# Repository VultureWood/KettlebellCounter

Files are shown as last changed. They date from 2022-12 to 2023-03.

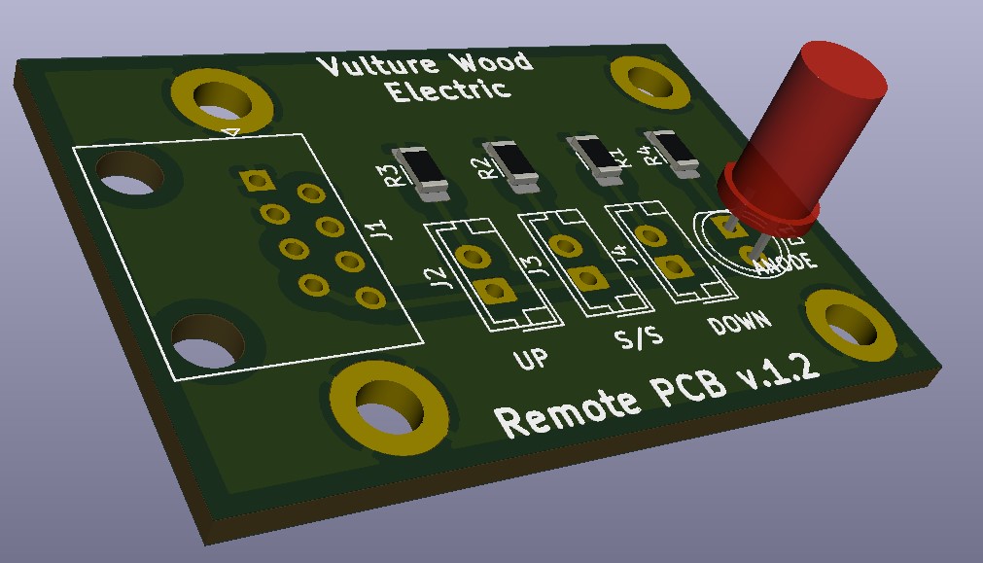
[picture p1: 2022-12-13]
PCB/Records/KBC_Remote/Remote_pcb_3d.jpg

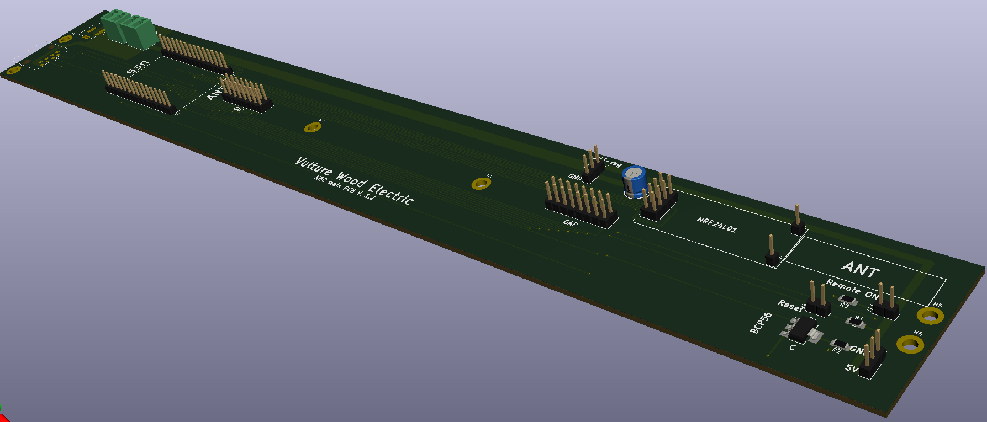
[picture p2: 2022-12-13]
PCB/Records/KBC_Main_PCB/KBC_Main_PCB_3d.png

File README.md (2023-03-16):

# KettlebellCounter
Open Source instruction and code, which allow any tech savvy kettlebell athlete to build their own counter.  

This project was my very first large scale project were I got to integrate all my skills obtained at DTU - Technical University of Denmark.  

The Kettlebell Counter project was a Start Up under DTU - Skylab and more than 100 counters have been sold.  
Obvious, looking back, the projects have its flaws and some solutions are not as refined or clever, as I would like to believe I could come up with now.  
However, the counters work and some have been used daily since 2019.  

I developed the counters for the 2019 IKMF European championship while I was finishing my M.Sc.EE at DTU.  

The counter is not just an up/down counter, it has lots of features like ladders, intervals and a dedicated pentathlon function, and it can be remote controlled by a radio link.  

My idea was that the counter could be used by the athlete for training as well as for competition, and everyone could bring their counters for a competition and they would all work together via remote control.
I’ve produced and sold the aforementioned 100+ counters in the frame of my start-up Company "Vulture Wood Electric", before getting an awesome job building radars, which came with a non-compete clause.  

I therefore closed the start-up, and after a 2 years grace periode, where no legal claims or injunctions have been filed, I can now freely share my project with the community.  

This project is share under the GitHub license, which like the Creative commons license, allows for free non-commercial use.  

The intent is for kettlebell enthusiasts to be able to build their own counter which can be used both for both individual training and competitions.  

Have fun and keep lifting  

Best regards  

Erik Hofman-Bang  
Denmark, December 2022.  

- Video instructions for PCB mounting with soldering instructions: https://youtu.be/9TzXEnOfvD8  

- Video instructions for modifying the 3D printed frame and assembly: "coming soon"

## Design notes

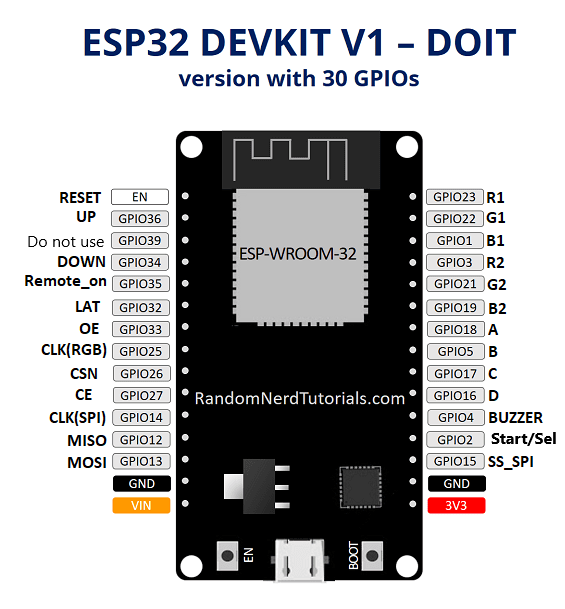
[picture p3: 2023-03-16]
Software_for_ESP32/ESP32-Pinout-for-VW_KBC_RGB_matrix_w_SPI.png

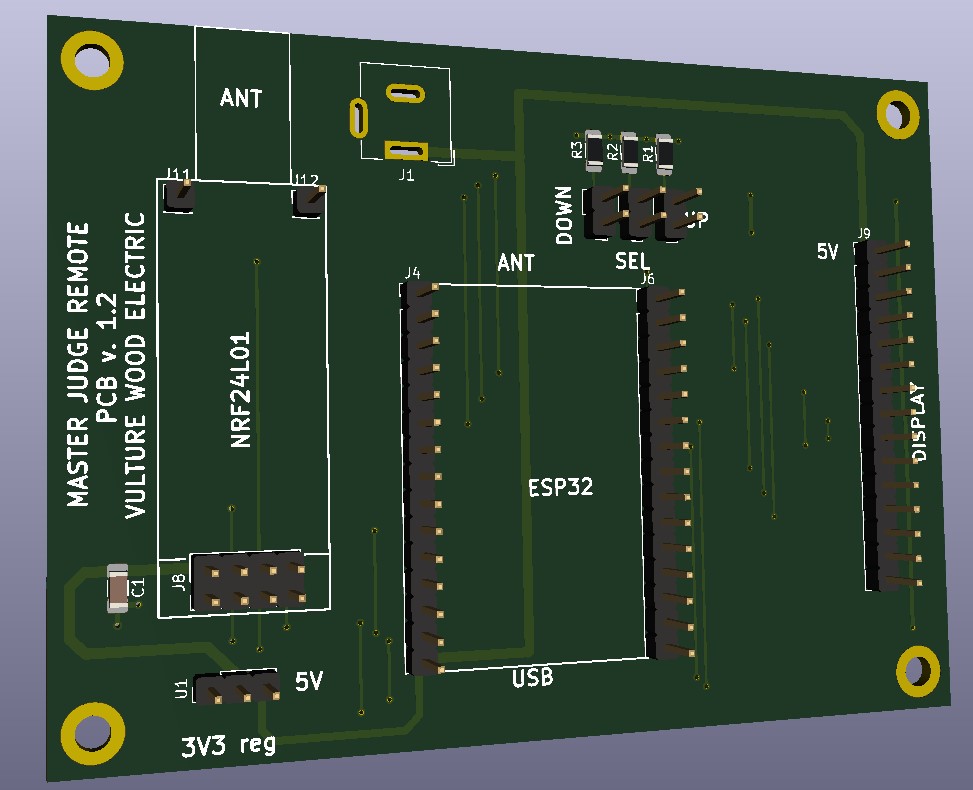
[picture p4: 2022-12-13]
PCB/Records/Master_Judge_Remote/Master_Judge_PCB_3D.jpg

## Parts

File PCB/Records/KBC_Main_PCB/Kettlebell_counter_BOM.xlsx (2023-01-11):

Reference Name | Value | Pieces | Comment | Aliexpress
MAIN PCB
U1 (J1/J2) | 1 x 15 pinHeader | 2 | 2.54 mm dupont female header 15 pins | https://www.aliexpress.com/item/32988745109.html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
R1,R2,R3 | 2.2k Ohm Resistor | 3 | 2k2 SMD 1206 resistor | https://www.aliexpress.com/item/1005001794416354.html?curPageLogUid=xTvxAzRKwdO4
J3,J6 | 2x8 Connector | 2 | IDC Box head connector for Ribbon cable 2x8 | https://www.aliexpress.com/item/1005004266492521.html?ad_pvid=20221128110945313599986753300016118840_3&s=p
J7 | Barrel Jack | 1 | 5.5 x 2.1 mm Female DC Power Jack Plug | https://www.aliexpress.com/item/4000585704812.html?spm=a2g0o.order_list.0.0.6a0f1802Q6Qj3E
J8 | 2 x 4 Pinheader | 1 | 2.54 mm dupont female header 8 pins (2x4) | https://www.aliexpress.com/item/32982421676.html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
J5,J12 | 2pin screw terminal | 2 | 2 pin Phoenix KF103 Screw terminal 5.08mm pitch | https://www.aliexpress.com/item/4000012676176.html?curPageLogUid=UXMHhe5J44D7
J10 | AMS1117-3.3V | 1 | 3 Pin PCB with AMS1117-3.3V and capacitors | https://www.aliexpress.com/item/32774098119.html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
J11 | RJ45 Plug | 1 | RJ45 Metal 8 Pin Female PCB | https://www.aliexpress.com/item/32694863099.html?pdp_ext_f=%7B%22sku_id%22%3A%2260585625209%22%7D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
C1 | 10uF | 1 | 10uF SMD 1206 capacitor, not necessary if capacitors on AMS117 | https://www.aliexpress.com/item/1005002532606555.html?curPageLogUid=5Q6LUYoGYaFm
Q1 | BCP56 | 1 | Transistor NPN BJT in SOT223 package | https://www.aliexpress.com/item/32714187815.html?spm=a2g0o.order_list.0.0.6a0f1802Q6Qj3E
H1-H6 | PCB Standoffs | 6 | Stand Offs, M3*18+6 | https://www.aliexpress.com/item/4000888322479.html?curPageLogUid=1wqWb8rG2vht
PCB | VW Main PCB V1.3 | 1 | The PCB for the Kettlebell Counter
MCU | ESP32-30 pin | 1 | ESP32 doit devkit v1 pinout | https://www.aliexpress.com/item/32864722159.html?spm=a2g0o.order_list.0.0.6a0f1802Q6Qj3E
Power Supply | 5V | 1 | 5V power supply. 2.5A current, and 5.5-2.5mm plug | https://www.aliexpress.com/item/33058333264.html?curPageLogUid=6rzwCtLGh5pI
 |  |  | Depending on you country. Select the plug and voltage suited
 |  |  | 2.5 A should be enough, normal current is ~2.1A, Choose a semi long wire >1m
Buzzer | 5 V Square | 1 | Round Piezoelectric buzzer | https://www.aliexpress.com/item/32783807336.html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
LED Screens | 64x32 P5 | 2 | LED Display P5 32*64 Pixles 320*160mm Panel 1/16 Scan Indoor RGB Full Color HUB75 | https://www.aliexpress.com/item/32870054325.html?spm=a2g0o.order_list.0.0.6a0f1802Q6Qj3E
Radio | NRF24L01 | 1 | Either the Base module with PCB antenna | https://www.aliexpress.com/item/1005004204908059.html?curPageLogUid=XcxRy4gxmFWM
 |  |  | or the extended with Big antenna, PA, and LNA | https://www.aliexpress.com/item/32831025394.html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
Reset Switch | button | 1 | Momentary push button, any kind will do. | https://www.aliexpress.com/item/1005004561204413.html?curPageLogUid=nWRDyEQSEv7G
Remote/local Switch | Flip Switch | 1 | On/OFF toggle switch, Any will do but I prefer this one: KNS-1 | https://www.aliexpress.com/item/33051456822.html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
Wires |  |  | Assorted wires for soldering swithces
NUT | 1/4-20 UNC | 1 | Hex nut 1/4" for mid frame, so tripod can be fixed | https://www.aliexpress.com/item/1005003345732578.html?curPageLogUid=IAchS2ZKnS4B
Bolt | 1/4-20 UNC | 1 | A bolt UNC 1/4-20, for driving the nut into it´s place in the mid frame | https://www.aliexpress.com/item/1005003504983409.html?curPageLogUid=XN0bGadiK4bz
Tripod | with 1/4-20 unc thread | 1 | Tripod to mount the counter on | https://www.aliexpress.com/item/1005003504983409.html?curPageLogUid=XN0bGadiK4bz
Remote
J11 | RJ45 Plug | 1 | RJ45 Metal 8 Pin Female PCB | https://www.aliexpress.com/item/32694863099.html?pdp_ext_f=%7B%22sku_id%22%3A%2260585625209%22%7D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
R1,R2,R3,R4 | 2.2k Ohm Resistor | 4 | 2k2 SMD 1206 resistor | https://www.aliexpress.com/item/32694862467.html?spm=a2g0o.order_list.0.0.6a0f1802Q6Qj3E
D1 | LED | 1 | 5mm LED with pre mounted wires and Holder | https://www.aliexpress.com/item/1005001992101233.html?curPageLogUid=z9fJW20eJ7ca
H1-H4 | PCB Standoffs | 4 | Stand Offs, M3*12+6 | https://www.aliexpress.com/item/4000888322479.html?curPageLogUid=1wqWb8rG2vht
PCB | Remote PCB V1.3 | 1 | The PCB for the Remote | Mounting holes a M3 (3.2mm) and spaced 30mm on the X axis and 22mm on the Y axis
 | M3 nuts | 4 | Nots for ocking the PCB in place
Cable | Cat 5 Patch | 1 | Ethernet Patch cable Straight through, NOT CROSSED, male-male, what ever length suits your purpose, Regardless of T-568B og T-568A. I choose this cable because it's cheap and available. I used T-568B cables but it shouldn't matter
Master Judge Remote
J4,J5,J9 | 1 x 15 pinHeader | 3 | 2.54 mm dupont female header 15 pins | https://www.aliexpress.com/item/32996636367.html?spm=a2g0o.order_list.0.0.6a0f1802Q6Qj3E
R1,R2,R3 | 2.2k Ohm Resistor | 3 | 2k2 SMD 1206 resistor | https://www.aliexpress.com/item/32694862467.html?spm=a2g0o.order_list.0.0.6a0f1802Q6Qj3E
J1 | Barrel Jack | 1 | 5.5 x 2.1 mm Female DC Power Jack Plug | https://www.aliexpress.com/item/4000585704812.html?spm=a2g0o.order_list.0.0.6a0f1802Q6Qj3E
H1-H4 | PCB Standoffs | 4 | Stand Offs, M3*18+6 | https://www.aliexpress.com/item/4000888322479.html?curPageLogUid=1wqWb8rG2vht
U1 | AMS1117-3.3V | 1 | 3 Pin PCB with AMS1117-3.3V and capacitors | https://www.aliexpress.com/item/32774098119.html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
C1 | 10uF | 1 | 10uF SMD 1206 capacitor, not necessary if capacitors on AMS117 | https://www.aliexpress.com/item/1005002532606555.html?curPageLogUid=5Q6LUYoGYaFm
J8 | 2 x 4 Pinheader | 1 | 2.54 mm dupont female header 8 pins (2x4) | https://www.aliexpress.com/item/32982421676.html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
Buttons | Push button | 3 | Momentary push button, any kind will do. | https://www.aliexpress.com/item/1005004561204413.html?curPageLogUid=nWRDyEQSEv7G
Display | 2,8" LCD Display | 1 | 2.8" 240x320 SPI TFT LCD | https://www.aliexpress.com/wholesale?catId=0&initiative_id=SB_20221130011202&origin=y
Extra | PCB Standoffs | 4 | Stand Offs, M3*18+6 +M3*12+6
Wires |  |  | Assorted wires for soldering swithces
Power Supply | 5V/2.5A | 1 | Important: the plug must match the Barrel jack DC 5.5-2.5 or DC 5.5-2.1 | https://www.aliexpress.com/item/33058333264.html?curPageLogUid=LnRn97kkHrKo

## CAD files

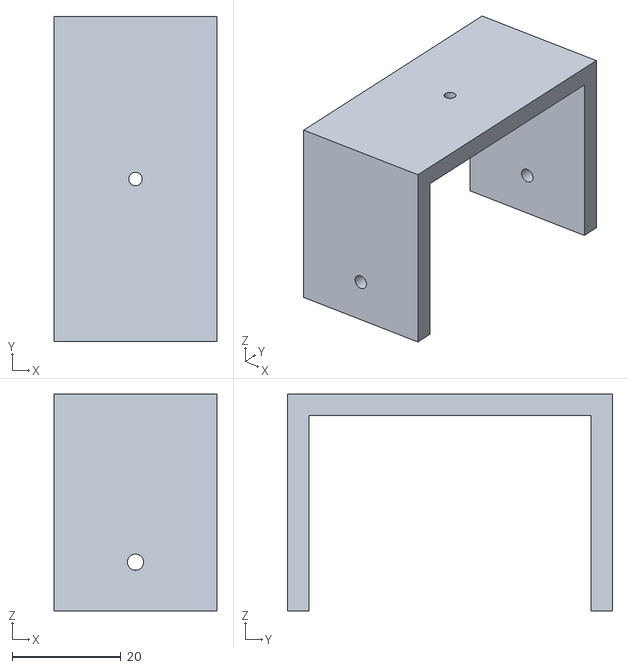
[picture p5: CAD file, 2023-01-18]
Mechanics/Frame_and_mounting_instructions/Top_Frame.stl
30.0 x 60.0 x 40.0

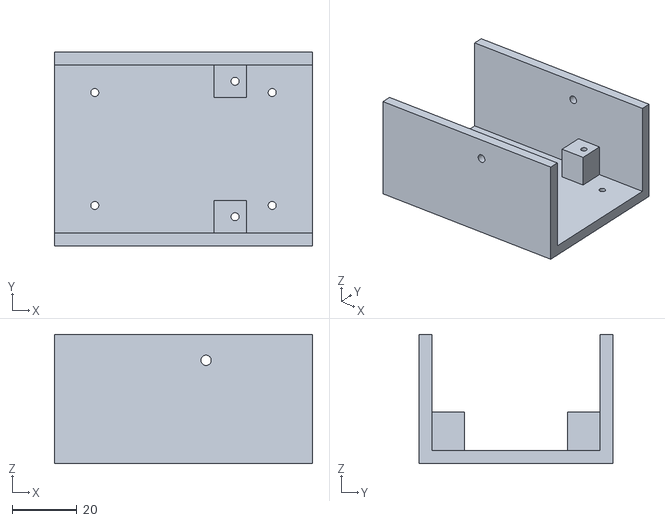
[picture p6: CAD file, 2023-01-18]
Mechanics/Frame_and_mounting_instructions/End_frame_R.stl
80.0 x 60.0 x 40.0

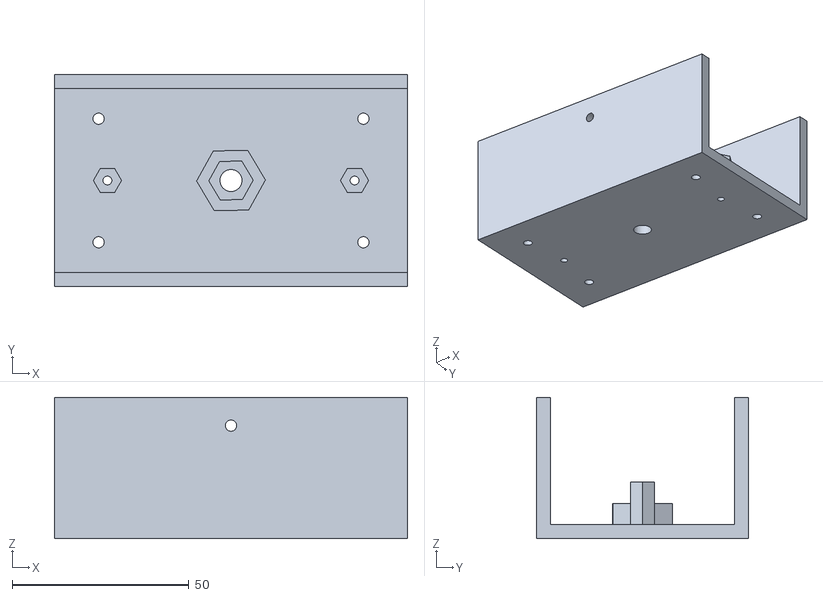
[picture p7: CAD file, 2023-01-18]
Mechanics/Frame_and_mounting_instructions/Mid_frame.stl
100.0 x 60.0 x 40.0

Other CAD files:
Mechanics/Frame_and_mounting_instructions/End_frame_L.stl

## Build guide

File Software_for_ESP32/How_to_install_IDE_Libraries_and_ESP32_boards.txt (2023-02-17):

Arduino IDE installation, Library download and board manager.

1) Arduino IDE:
Go to Arduino.cc and download the IDE to your computer. 
Follow the step shown, it should be staright forward, even with the new 2.0 IDE.

2) Libraries
Open you browser, and search for:

Adafruit_GFX.h.

Click the GitHub link. press the Green <Code> button , and select "downlaod ZIP"

Do this for:

RF24.h  (by nRF24) and P3RGB64x32MatrixPanel.h (by NeoCat) as well

Go to your Aarduino IDE again, and select: <Sketch> , <Include Library>, < Add .zip Library..>

A file explorer window (or similar) will open. Navigate to your downlaod folder and select one of the above mentioned files and click <Open>

Repeat this for the remaining two files 

3) adding ESP 32 boards to the IDE

Press <FileZ in the top left corner of the IDE, and select <Prefrences>

Almost at the bottom, insert "https://dl.espressif.com/dl/package_esp32_index.json" into the text field after "Additional boards manager URLs:

Press <OK>

Go to <Tools> , <Board:> and select <Boardmanager>

Tyoe in "ESP32" in to the text field in the top left corner under "BOARDS MANAGER" and press enter

PRess the "esp32 by Espressif Systems" and select the newest version to installation

4) Selecting the right board

Go to <Tools> , <Board:> , <esp32> and select the right ESP32 board. For me its "DOIT ESP32 DEVKIT V1"

You should now be able to compile the file.

When uploading... Remember that once it starts the actual uploading, the IDE polls the board, and you have to

press the "BOOT" button on the right side of the USB port to enable the upload procedure.

17/02-23 

\\Erik

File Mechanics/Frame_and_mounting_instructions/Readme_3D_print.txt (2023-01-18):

Print:

1x End_frame_Right.stl

1x End_frame_Left.stl

1x Mid_frame.stl

2x Top_Frame.stl

5 layer walls. PLA, 50% infill

Use Brim for support

Materials:

5 x 3D printed parts
2 x LED Matrix scrrens 64x32 P5
2 x Ribbon cables
1 x power cable
10 x M3x10 Socket head screws
6 x M3x6 button head screws
1 x 1/4-20 UNC Nut

Tools:
1 x 1/4-20 UNC Bolt , 1" or longer
Power drill
2.5mm drill
3.5mm drill
M3 Tap
11mm Wrench/Spanner 

Mounting:
Pre drill all vertical holes for M3 with a 2.5mm drill and then cut a thread with a M3 tap all the way through 
( 6 in each of the bottom parts, and 1 in each of the top part))

Drill all horizontal "screen mounitng holes" with a 3.2mm (3.5mm) drill ( 2 in each piece)

Mount a 1/4-20 UNC hex nut, with a 1/4-20 UNC bolt from the backside and force the nut into the hex shape in the MID_frame.

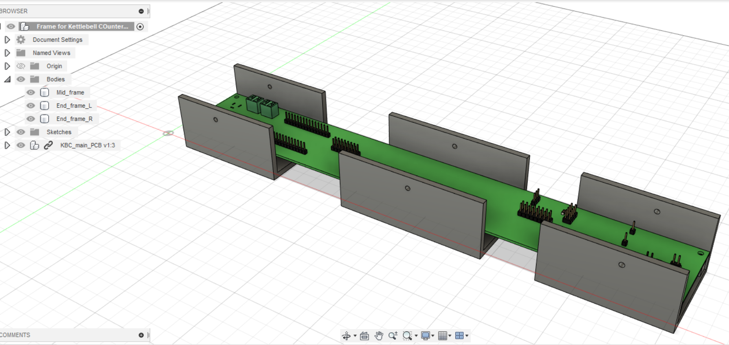
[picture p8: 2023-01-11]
Mechanics/CAD-files/Frame_3D_printed/Bottom_frames_and_PCB_principal_assembly.png

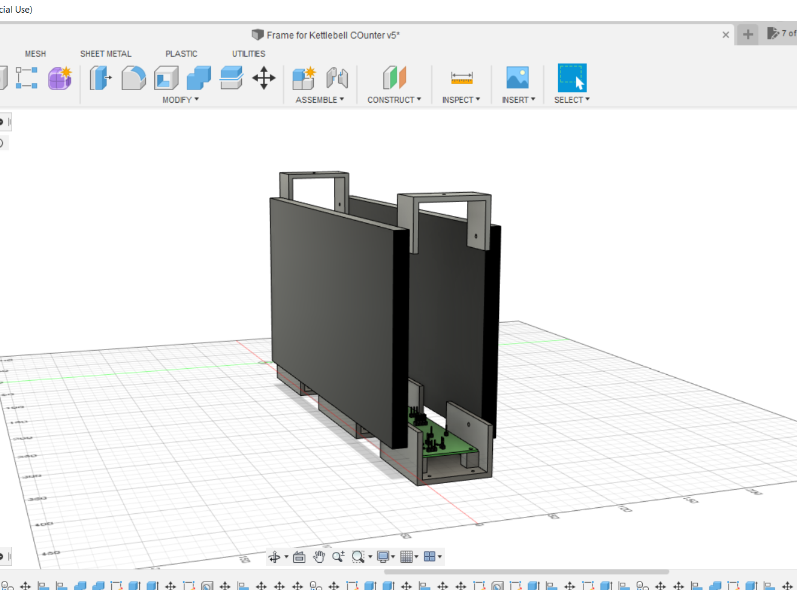
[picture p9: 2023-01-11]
Mechanics/CAD-files/Frame_3D_printed/Insta_pic_1.png

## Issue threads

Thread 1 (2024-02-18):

Frame and case for Master Judge remote

langatium, 2024-02-18:
I'm wondering if you could share details (casing and frame) for the master judge remote?

Vulture-in-the-woods, 2024-02-19:
Hi Heinz-Peter.
Thank you for your interest.
I currently have the project on hold while I’m doing a very large project, which takes up all my time and resources.
I have planed to review the whole design and project sometime this summer, but until the I’m unfortunately unable to accommodate your request.
Best Regards
Erik

langatium, 2024-02-19:
Hi Erik,

no worries, all best for your large project. Nevertheless big thanks for sharing the design of your timer. I'm nearly finished with the first one.

Best regards
Heinz

Vulture-in-the-woods, 2024-02-19:
That’s really great Heinz.
I’m so glad that people are building by the timers, although I didn’t get to finish all details.
Please let me know once you’ve build your timer. I’m in instagram as @vulturewood
//Erik

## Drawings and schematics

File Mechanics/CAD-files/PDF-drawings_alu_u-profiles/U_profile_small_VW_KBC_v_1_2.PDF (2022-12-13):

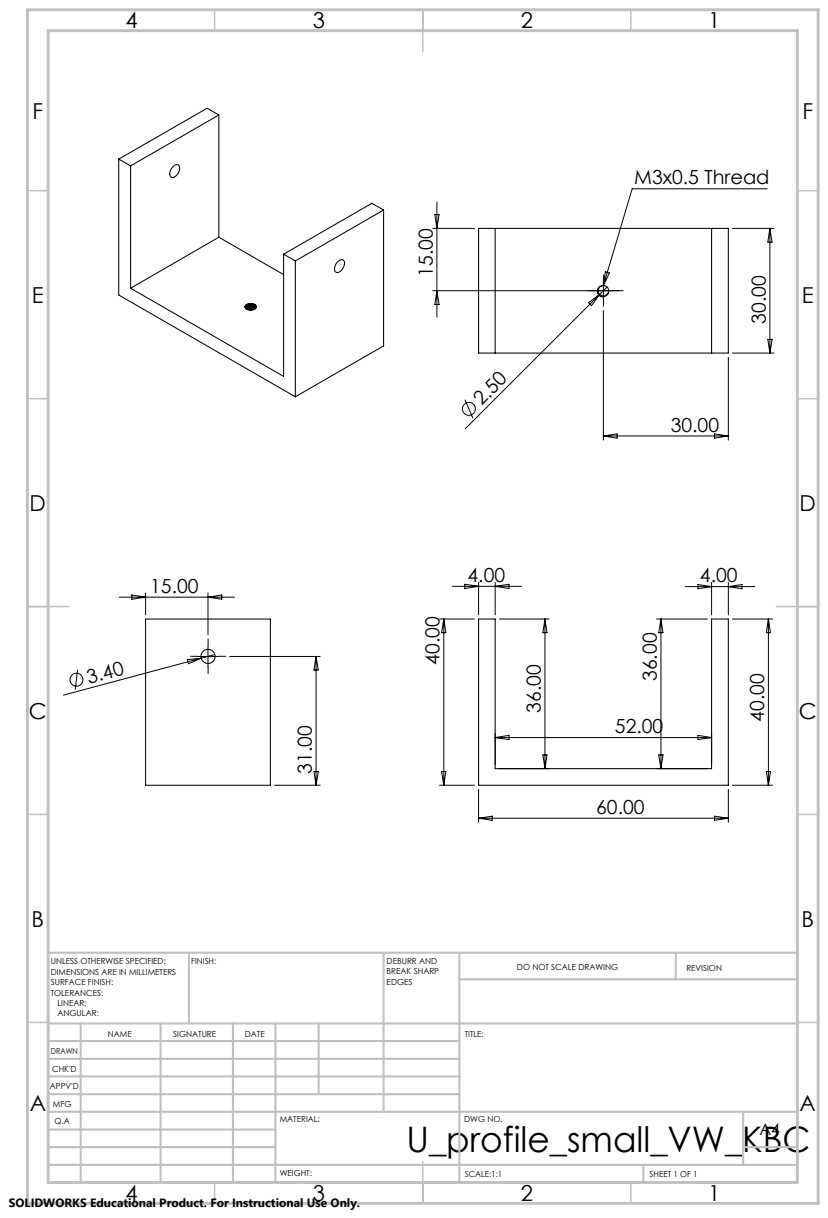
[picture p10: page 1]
M3x0.5 Thread; FINISH:; DEBURR AND; BREAK SHARP; DO NOT SCALE DRAWING; REVISION; SCALE:1:1; SHEET 1 OF 1

UNLESS OTHERWISE SPECIFIED:
DIMENSIONS ARE IN MILLIMETERS
SURFACE FINISH:
TOLERANCES:
LINEAR:
ANGULAR:

NAME | SIGNATURE | DATE | | | | TITLE:

DRAWN
CHK'D
APPV'D
MFG
Q.A | | | | MATERIAL: U_profile_small_VW_KBC | DWG NO. | A4

SOLIDWORKS Educational Product. For Instructional Use Only.

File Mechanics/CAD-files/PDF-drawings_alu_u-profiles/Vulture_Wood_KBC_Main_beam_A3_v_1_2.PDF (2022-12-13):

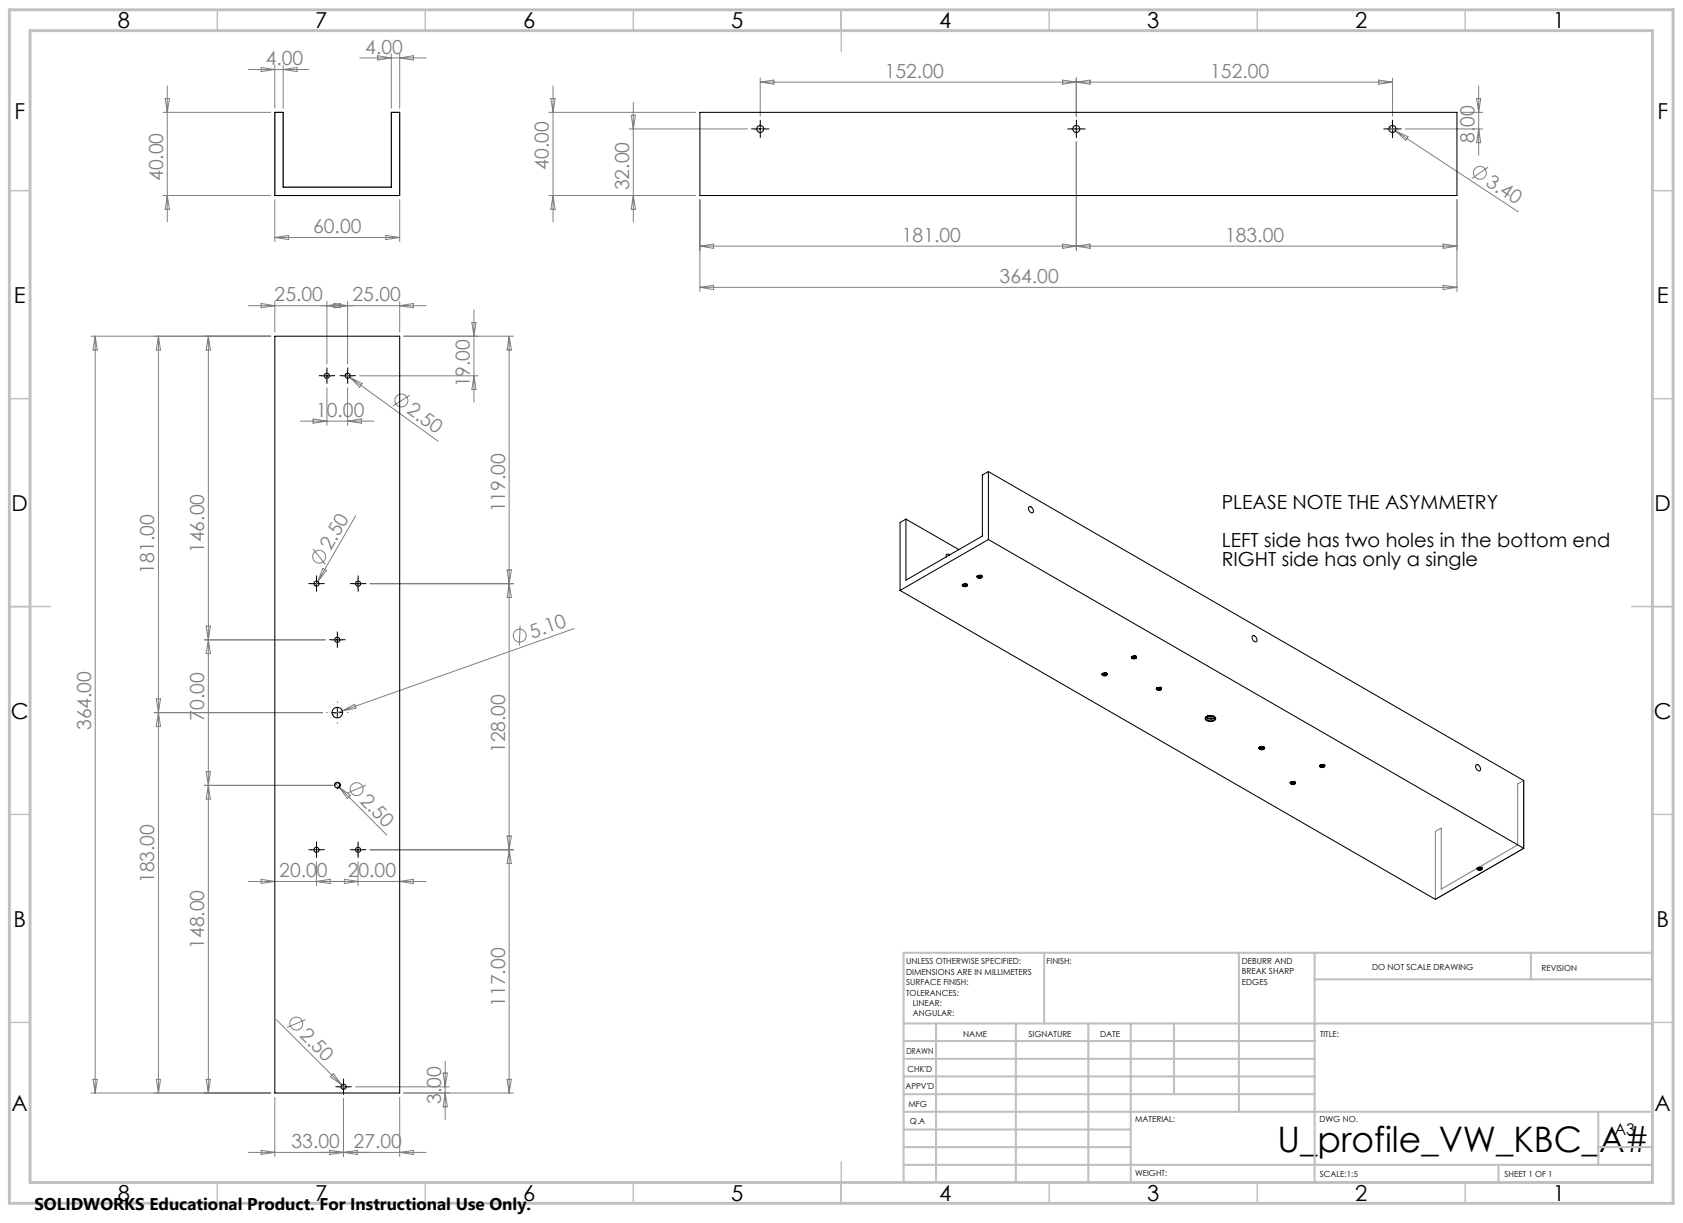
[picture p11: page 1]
FINISH:; DEBURR AND; BREAK SHARP; DO NOT SCALE DRAWING; REVISION; SCALE:1:5; SHEET 1 OF 1

PLEASE NOTE THE ASYMMETRY
LEFT side has two holes in the bottom end
RIGHT side has only a single

UNLESS OTHERWISE SPECIFIED:
DIMENSIONS ARE IN MILLIMETERS
SURFACE FINISH:
TOLERANCES:
LINEAR:
ANGULAR:

NAME | SIGNATURE | DATE | | | | TITLE:

DRAWN
CHK'D
APPV'D
MFG
Q.A | | | | MATERIAL: U_profile_VW_KBC_A# | DWG NO. | A3

SOLIDWORKS Educational Product. For Instructional Use Only.

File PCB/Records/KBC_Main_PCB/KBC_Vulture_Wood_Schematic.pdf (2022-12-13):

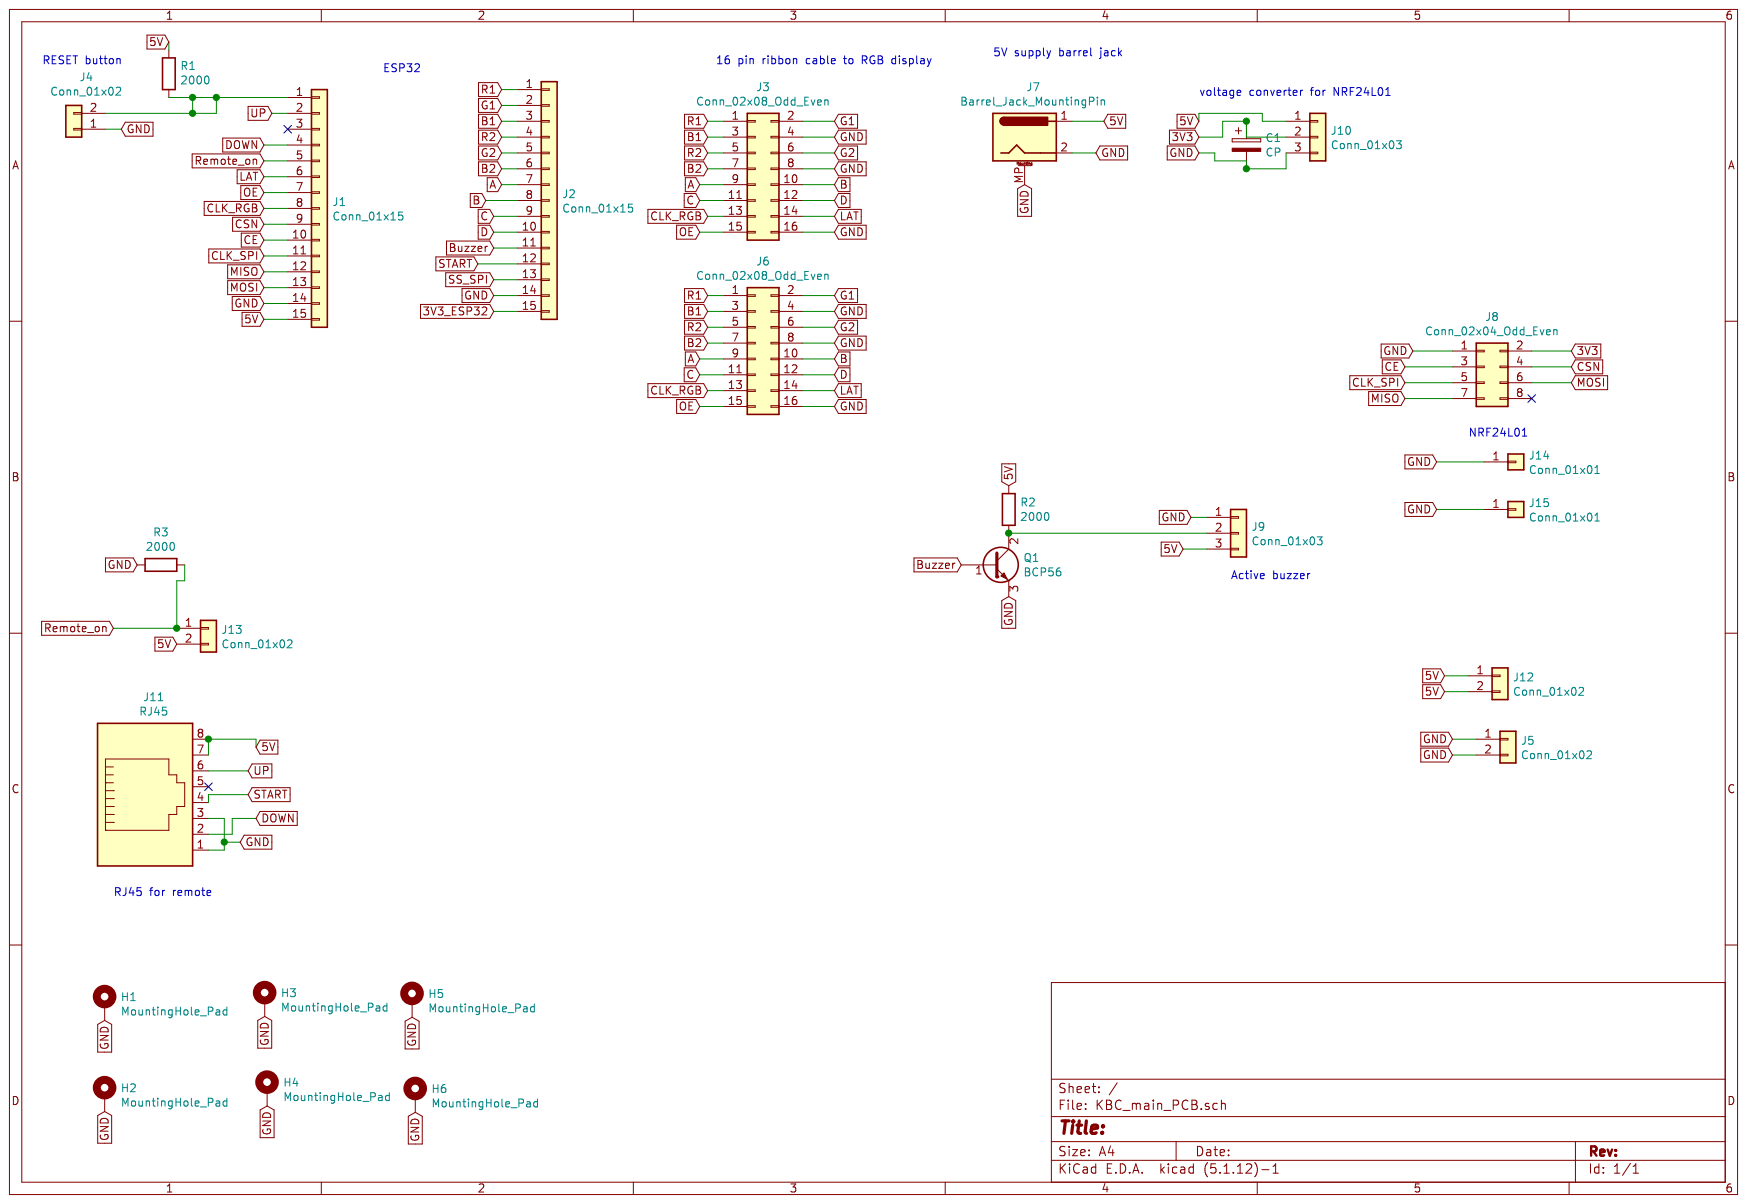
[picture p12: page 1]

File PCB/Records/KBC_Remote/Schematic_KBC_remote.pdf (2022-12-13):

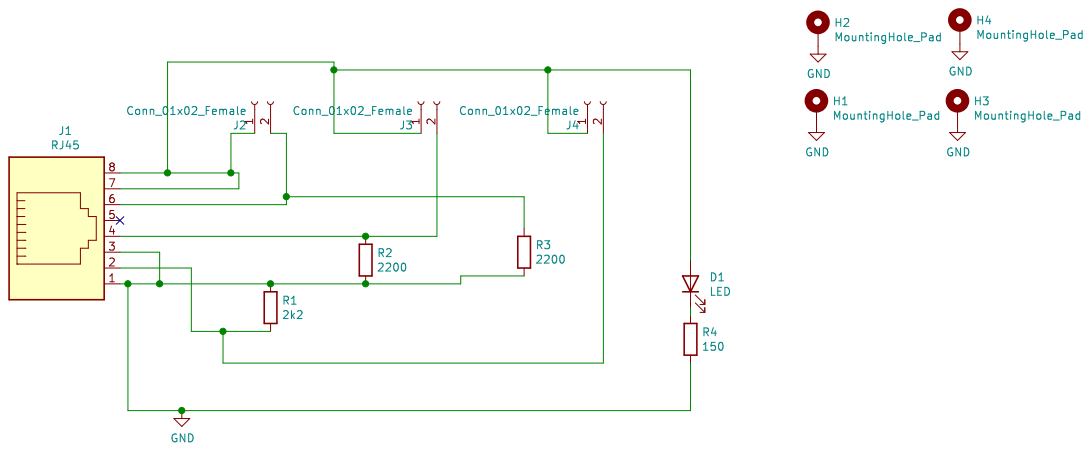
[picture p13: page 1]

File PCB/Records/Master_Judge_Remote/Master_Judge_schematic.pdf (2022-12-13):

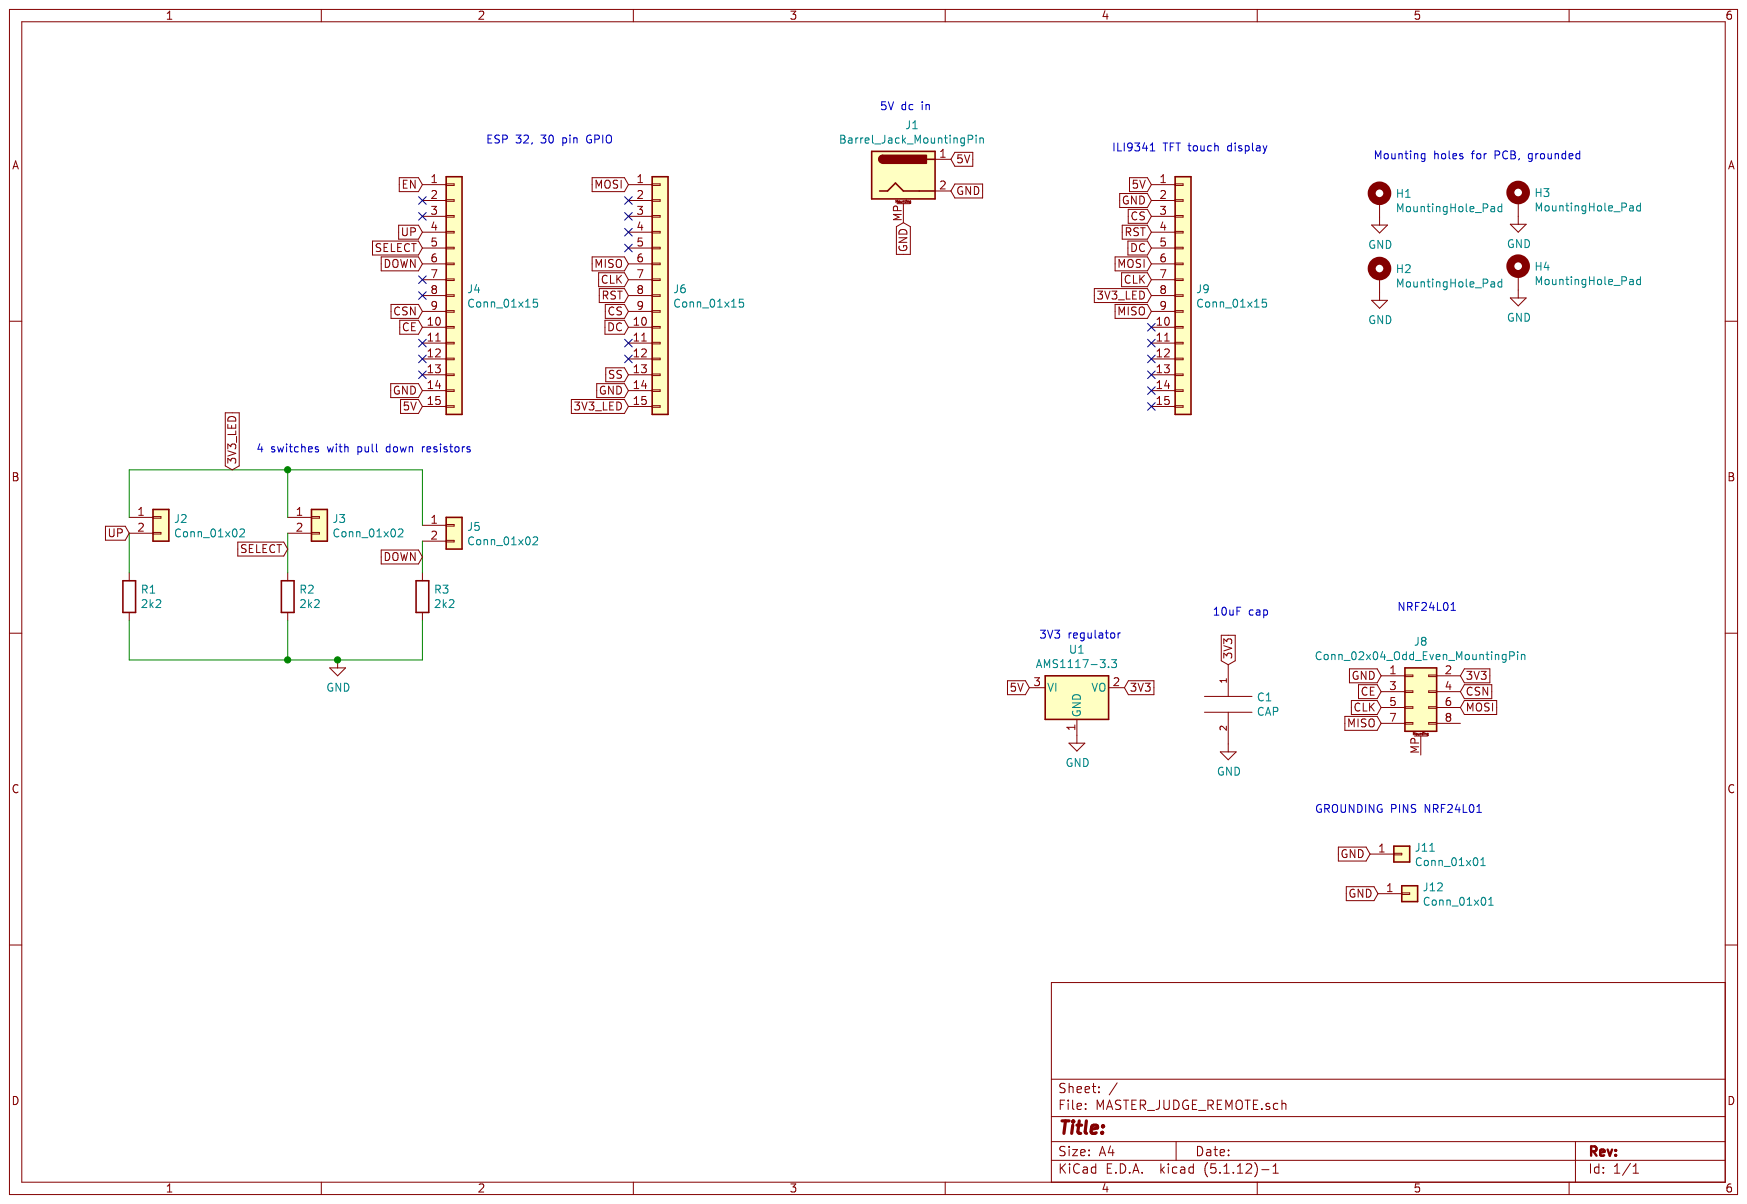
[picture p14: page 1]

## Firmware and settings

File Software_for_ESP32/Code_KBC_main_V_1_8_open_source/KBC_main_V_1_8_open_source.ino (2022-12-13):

/*
This code is the work of Erik Hofman-Bang, Denmark (the author)
For the project known as Vulture Wood Electric
These next ~4400 lines make up the main Kettlebell Counter including:
Base functions and Remote operation via radio/SPI link
Bluetooth functions have been erased, but as of 30/11-22 the menu point still exists 
This code is designed for an ESP32 and takes up 23% of storage and 4 % o dynamic memory

This code can be used and/or altered under the creative Commons license for all non-commercial purposes if the author is credited
*/

#include <Adafruit_GFX.h>   // Core graphics library
#include <P3RGB64x32MatrixPanel.h> // RGB display driver from NEOCAT github
// That is the library which contains the matrix.begin(); command which makes the watchdog timer panic
#include <SPI.h> // spi for radio use
#include <nRF24L01.h> // radio libraries
#include <RF24.h> // radio libraries  // 

// Radio pins
#define CE_PIN  27
#define CSN_PIN 26  
#define CLK_SPI 14 // 
#define MISO 12 // 
#define MOSI 13 //
#define SS 15 // 

//Matrix pins
#define R1 23
#define G1 22
#define BL1 1
#define R2 3
#define G2 21
#define BL2 19
#define pin_A 18
#define pin_B 5
#define pin_C 17
#define pin_D 16
#define CLK_RGB 25
#define LAT_RGB 32
#define OE_RGB 33

//////////////////////////////////////////////////////////
//
//  RADIO SPECIFIC VARIABLES ETC
//
//////////////////////////////////////////////////////////

bool doOnceRadio = true;
bool rpdPrint;
RF24 radio(CE_PIN,CSN_PIN);

unsigned long timeDifference;

const uint64_t pipe1 = 0xE8E8EEF0A1LL;;
const uint64_t pipe2 = 0xA2LL;  
const uint64_t pipe3 = 0xA3LL;
const uint64_t pipe4 = 0xA4LL;
const uint64_t pipe5 = 0xA5LL;
const uint64_t pipe6 = 0xA6LL;

// RADIO memory string

typedef struct {
  char filterChar[1];
  bool startBit;
  bool reset1;
  uint8_t setDiscipline;
  unsigned long setDuration;
  unsigned long masterMillis;
  bool returnResult;
  uint16_t result;
  bool switchChannel;
  bool reset2;
  } TXstruct;

  TXstruct message;
  TXstruct validMessage;

  // Matrix pin constructor
  //P3RGB64x32MatrixPanel matrix; // default constructor
P3RGB64x32MatrixPanel matrix(R1,G1,BL1,R2,G2,BL2,CLK_RGB,LAT_RGB,OE_RGB,pin_A,pin_B,pin_C,pin_D);

//////////////////////////////////////////
//
// Butten and buzzer pins
//
/////////////////////////////////////////

#define buttonPin 2   // select/menu
#define repButtonUP 36
#define repButtonDOWN 34
#define remote_on 35
#define BuzzerPin 4
uint16_t Buzzerfreq = 2000;
uint8_t BuzzerChannel = 0;
uint8_t BuzzerResolution = 8;
uint16_t BuzzerDuty = 128; // Volumen intensity in 8 bits, 125 (50%) will be loudest I think)

/////////////////////////////////////
//
// Variables for general functions.
//
////////////////////////////////////

int8_t countState = LOW;         // the current state of the output pin
int8_t buttonState;             // the current reading from the input pin
int8_t lastButtonState = LOW;   // the previous reading from the input pin
int8_t buttonStateRepUP;             // the current reading from the input pin
int8_t lastButtonStateRepUP = LOW; 
int8_t buttonStateRepDOWN;             // the current reading from the input pin
int8_t lastButtonStateRepDOWN = LOW; 
int8_t readingRepUP;
int8_t readingRepDOWN;
int8_t reading;
int8_t readingONEmenuUP;
long lastDebounceTimeONEmenuUP;
int8_t buttonStateONEmenuUP = 0;
int8_t lastbuttonStateONEmenuUP = 0;
uint8_t line; // for time_fractionPause
int8_t Menu = 1;
int8_t Select =0;
int8_t choiceMade =0;
uint16_t sum_CLEAN = 0;
uint16_t sum_CandP = 0;
uint16_t sum_JERK = 0;
uint16_t sum_HS = 0;
uint16_t sum_PP = 0;
uint16_t divider = 0 ;
int8_t run_pause=0;
int8_t doOnceTimer=1;
int8_t doOnceCounter=1;
int8_t doOnceCountdownTimer =1;
int8_t doOnceRepCounter = 0;  // for testing rep numbers
int8_t runStopRoutine =1;
int8_t CDT_hh_1 = 0;
int8_t CDT_mm_10 = 0;
int8_t CDT_mm_1 = 0;
int8_t CDT_ss_10 = 0;
int8_t CDT_ss_1 = 0;
int8_t CDT_menu = 1;
int8_t CDT_menu_Last =1;
int8_t CDT_var_val =0;
int8_t fourDigits = 0;
int8_t Pentathlon = 0;
int8_t doOncePentathlon =1;
int8_t Countdown = 0;
int8_t UPdownMenu =0;
uint8_t ONEmenuUP  =0;
int8_t doOnceUPdownMenu =1;
int8_t UpDown_var_val = 2;
int8_t doOnceCountdown =1;
int8_t setCountdownTimer =1;
int8_t CountdownTimer = 0;
int8_t CountUpTimer = 0 ;
int8_t Interval = 0;
int8_t doOnceInterval =1;
uint8_t XonYoff = 0;
int XOnctr = 1;
int XOntime = 60;
int XOntimeOLD = 0;
int YOffctr = 1;
int YOfftime = 60;
int YOfftimeOLD = 0;
int XOnYOffctr = 0;
uint8_t doOnceYOfftimeRUN = 1;
int16_t XonYoffRounds =1; 
int16_t XonYoffRoundsOLD =0; 
uint8_t doOnceXonYoff = 1;
uint8_t XOnYOfftimer =0;
uint8_t doOnceXOnYOfftimer = 1;
uint8_t XOntimeRUN = 1;
uint8_t YOfftimeRUN = 1;
uint8_t doOnceEndXOnYOff =1;
uint8_t MERKULIN = 0;
uint8_t EMOTM = 0;
uint8_t EMOTMtimer = 0;
uint8_t endOfEMOTM = 0;
uint8_t disciplineDisplay = 1;
uint8_t durationDisplay =0;
uint8_t doOnceremote =1;
uint8_t waitingForStartCommand = 1;
uint8_t DisciplineNOTset =1;

uint16_t sum_MERKULIN[]= {0,0,0,0,0,0,0,0,0,0,0,0,0,0,0,0,0,0,0,0,0,0,0,0,0,0,0,0,0,0,0,0,0,0,0,0,0,0,0,0,0,0,0,0,0,0,0,0,0,0,0,0,0,0,0,0,0,0,0,0,0,0,0,0,0,0,0,0,0,0,0,0,0,0,0,0,0,0,0,0,0,0,0,0,0,0,0,0,0,0,0,0,0,0,0,0,0,0,0,0,0,0};
uint8_t doOnceMERKULIN =1;
uint8_t MiddleMERKULINstep;
uint8_t UNEVEN = 0;
uint8_t UNEVENctr =0;
int8_t UNEVENrounds = 1;
int8_t UNEVENitteration = 1;
int16_t UNEVENtime =1;
int16_t UNEVENtimeTEN = 10;
uint8_t UNEVENtime_mm_10;
uint8_t UNEVENtime_mm_1;
uint8_t UNEVENtime_ss_10 = 1;
int16_t UNEVENdecrement = 0;
uint8_t UNEVENdecrement_mm_1;
uint8_t UNEVENdecrement_ss_10;
uint8_t UNEVENdecrement_ss_1;
uint8_t doOnceUNEVENmenu5 = 1;
uint16_t lastUNEVENtime;
uint16_t lastUNEVENdecrement;
uint8_t MERKULINtimer = 0;
uint8_t UNEVENtimer =0;
uint16_t PauseSteps;
uint16_t PauseStepsOLD;
uint8_t doOnceMERKULINtimer = 1;
uint8_t LADDERS = 0;
uint8_t doOnceLadders =1;
uint8_t UNEVENup =0;
uint8_t UNEVENdown =0;
uint8_t doOnceUneven =1;
uint8_t TABATA = 0;
uint8_t TABATAtimer = 0;
uint8_t doOnceTABATAendResult =1;
int TabataOntime;
int TabataOntimeOLD;
int TabataOfftime;
int TabataOfftimeOLD;
int TabataRounds;
int TabataRoundsOLD;
int TabataItterations;
int TabataItterationsOLD;
int bigTABATAbreak;
uint8_t choiceMadeInterval =0 ;
int8_t BLUETOOTH = 0;
int8_t remote = 0;
int8_t horn_offset = 50; // ændre tilbage til 50
int8_t hh_1_old = 10;
int8_t mm_10_old = 10;
int8_t mm_1_old = 10;
int8_t ss_10_old = 10;
int8_t ss_1_old = 10;
int i;
int k;
unsigned long lastDebounceTime = 0;  // the last time the output pin was toggled
unsigned long debounceDelay = 20;    // the debounce time; increase if the output flickers
unsigned long ss_10 = 0;
unsigned long ss_1 = 0;
long sum_CDT =0;
long repCounter = 0;
long lastRepWas = 0;
long timer_total;
long XOntimeTimeHolder;
long YOfftimeTimeHolder;
unsigned long mm_10 = 0;
unsigned long mm_1 = 0;
unsigned long hh_10 = 0; 
unsigned long hh_1 = 0;
long hours_10 = 36000000;
long hours_1 = 3600000;
long minutes_10 = 600000;
long minutes_1 = 60000;
long seconds_10 = 10000;
long seconds_1 = 1000;
long startMillis = 0;
long currentMillis = 0 ;
long timerSet = 3000000; //50*60*1000
long difference_millis;
long intermediate_millis;
unsigned long timeHolder1 = 0;
unsigned long timeHolder2 = 0;    


void RadioStartUp(){
  SPI.begin(CLK_SPI,MISO,MOSI,SS);
  
  radio.begin();
  radio.openReadingPipe(1,pipe1); // (1, const uint8_t *address) Pipe number (usually 1), pipe address (which is usually 5 bytes in an array structure).
  radio.setPALevel(RF24_PA_MIN); // RF24_PA_MIN, RF24_PA_LOW, RF24_PA_HIGH and RF24_PA_MAX
  radio.setDataRate(RF24_2MBPS); // 500kBPS 1MBPS   2MBPS
  //radio.enableAckPayload();
  //radio.setRetries(15,15);
  radio.setChannel(108); // 0-124
  //radio.powerUp();
  radio.startListening();
  delay(5);
      }

void RadioRestart(){
        radio.startListening();
        delay(5);    
        }

void RadioListenandSave(){
    if (radio.available()) {    
      //Serial.println("radio is available: ");
    radio.read(&message, sizeof(message));
    timeDifference = message.masterMillis-millis();
    if(message.filterChar[0]=='H'){
    validMessage = message;
    }
    } 
  }


////////////////////////////////////////////////////////
//
//             SETUP
//
/////////////////////////////////////////////////////////
  
void setup(){  
   //Serial.begin(115200);
   RadioStartUp(); // Setup of radio functions and parameters
   //Serial.println("Serial startup");

   
 ///////////////////////////////
// Setting up buzzer and buttons
//////////////////////////////

  ledcSetup(BuzzerChannel, Buzzerfreq, BuzzerResolution);

  
  ledcAttachPin(BuzzerPin, BuzzerChannel);   // remember to UNCOMMENT after test

  
  pinMode(repButtonUP, INPUT); // Counter increment
  pinMode(repButtonDOWN, INPUT); // Counter decrement
  pinMode(buttonPin, INPUT); // Start/Stop
  pinMode(remote_on, INPUT); // remote on/off

 remote = digitalRead(remote_on);
 
 
  
///////////////////////////////////
// Initialize Matrix
//////////////////////////////////
  matrix.begin();
  matrix.setTextWrap(false); // Don't wrap at end of line - will do ourselves
 if(!remote){
  startUpText();
  printMainMenu();
 } // End if(!remote)

  if(remote){
  matrix.fillScreen(matrix.color444(0, 0, 0)); //Clear screen
  matrix.setTextSize(1);  
  matrix.setTextColor(matrix.color555(31,0,0));
  matrix.setCursor(14, 12); 
  matrix.println("REMOTE");
  delay(5000); // 5000
  } // end if(remote)

  } // end of void setup

////////////////////////////////////////////////////////////
//
//    MAIN LOOP
//
/////////////////////////////////////////////////////////////

 
void loop() {

////////////////////////////////
//
// REMOTE sequence
//
///////////////////////////////
if(remote){

  if(doOnceremote){
  matrix.stop(); // matrix has to stop before SPI for the NRF24L01 Radio
  RadioRestart(); // Restart the radio, ready to listen
  doOnceremote = 0;
  }
  
  while(DisciplineNOTset){
  RadioListenandSave(); // Listen and save if something is incoming

  if(validMessage.filterChar[0]=='H' && disciplineDisplay){
     matrix.fillScreen(matrix.color444(0, 0, 0)); //Clear screen
    matrix.setTextColor(matrix.color555(1,31,1));
    if(validMessage.setDiscipline==1){
      matrix.begin(); // Restart the matrix
        matrix.setCursor(1, 16); 
        matrix.println("COUNT DOWN");
        disciplineDisplay=0;
        durationDisplay = 1;
         delay(2000);
      }

       if(validMessage.setDiscipline==2){
        matrix.begin(); // Restart the matrix
        matrix.setCursor(8, 16); 
        matrix.println("COUNT UP");
        disciplineDisplay=0;
        durationDisplay = 1;
        delay(2000);
      }

       if(validMessage.setDiscipline==3){
        matrix.begin(); // Restart the matrix
        matrix.setCursor(2, 16); 
        matrix.println("PENTATHLON");
        disciplineDisplay=0;
        durationDisplay = 1;
        delay(2000);
      }
  }
   
   matrix.fillScreen(matrix.color444(0, 0, 0)); //Clear screen
  
   if(validMessage.filterChar[0]=='H' && durationDisplay){

      if(validMessage.setDuration >= 3600000){ // IF timer is larger than 1 hour, set 5 digits
           doOnceTimer=1;
           }
            if(validMessage.setDuration < 3600000){ // IF timer is less than 1 hour, set 4 digits
           fourDigits=1;
           doOnceTimer=1;
           }

           // PRINT THE DURATION ON SCREEN
           
    time_fractionCountdown(validMessage.setDuration,14); // 14 is the line it's written on 
     delay(2000);
      DisciplineNOTset = 0;
      doOnceremote=1;
    }
    
     } // end of while(DisciplineNOTset)
     

   while(waitingForStartCommand){  
   if(doOnceremote){
  matrix.stop();
  RadioRestart(); // Restart the radio, ready to listen
  doOnceremote = 0;
  }
    RadioListenandSave(); // Listen and save if something is incoming
  //Serial.println("waitingForStartCommand");
   if(validMessage.filterChar[0]=='H'){
    //Serial.print("validMessage.startBit ");
    //Serial.println(validMessage.startBit);
   
    if(validMessage.startBit == 1){
   
    // count down instructions
      if(validMessage.setDiscipline==1){
   Countdown = 1;  // go to countdown
   CountdownTimer =1 ; // GO TO countdown timer
   setCountdownTimer = 0;  // skip SET COUNT DOWN TIMER
   UPdownMenu = 0; // skip UP DOWN MENU
   waitingForStartCommand = 0; // leave this loop
   matrix.begin();
   timeHolder1=validMessage.setDuration;
      }
// Count up instructions
      if(validMessage.setDiscipline==2){
   Countdown = 1;  // go to countdown
   CountUpTimer =1 ; // GO TO countdown timer
   setCountdownTimer = 0;  // skip SET COUNT DOWN TIMER
   UPdownMenu = 0; // skip UP DOWN MENU
   waitingForStartCommand = 0; // leave this loop
   matrix.begin();
   timeHolder1=validMessage.setDuration;
      }

// pentathlon instructions
      if(validMessage.setDiscipline==3){
   Pentathlon = 1;  // go to pentathlon
   countState = 1;
   waitingForStartCommand = 0; // leave this loop
   matrix.begin();
   timeHolder1=validMessage.setDuration;
      }
      
    } // end of if(validMessage.startBit == 1)
   } // end of if(validMessage.filterChar[0]=='H')
   }
} // end if (remote)
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
} // end of void loop()


///////////////////////////////////////////////////////
//
// Functions 
//
///////////////////////////////////////////////////////


void endResult(){
  int R = 1;
  int G = 15;
  int B = 31;
  matrix.fillScreen(matrix.color444(0, 0, 0));
    matrix.setTextColor(matrix.color555(R,G,B)); 
    matrix.setTextSize(1);
    matrix.setCursor(1,1);
    matrix.print("C");

    matrix.setTextColor(matrix.color555(0,16,0)); 
    matrix.setCursor(9,1);
    matrix.print(sum_CLEAN);
    matrix.setTextColor(matrix.color555(R,G,B)); 
    matrix.setCursor(1,13);
    matrix.print("CP");

    matrix.setTextColor(matrix.color555(0,16,0)); 
    matrix.setCursor(15,13);
    matrix.print(sum_CandP);
    matrix.setTextColor(matrix.color555(R,G,B)); 
    matrix.setCursor(1,24);
    matrix.print("J");

    matrix.setTextColor(matrix.color555(0,16,0)); 
    matrix.setCursor(9,24);
    matrix.print(sum_JERK);
    matrix.setTextColor(matrix.color555(R,G,B)); 
    matrix.setCursor(33,7);
    matrix.print("HS");

    matrix.setTextColor(matrix.color555(0,16,0)); 
    matrix.setCursor(46,7);
    matrix.print(sum_HS);
    matrix.setTextColor(matrix.color555(R,G,B)); 
    matrix.setCursor(33,19);
    matrix.print("PP");

    matrix.setTextColor(matrix.color555(0,16,0)); 
    matrix.setCursor(46,19);
    matrix.print(sum_PP);
  }

  
int pause(){
  doOnceTimer = 1;
   matrix.fillScreen(matrix.color444(0, 0, 0)); //Clear screen
   matrix.setTextSize(1); 
   matrix.setTextColor(matrix.color555(1,31,1));
   matrix.setCursor(18, 0);
   matrix.print("PAUSE");
  // Serial.println("Pause funtion called");
  }

// countdown clock and buzzer
    void countDownToStart(){
      matrix.setTextSize(1); 
   long  MystartMillis = millis();
   matrix.fillScreen(matrix.color444(0, 0, 0));  // Clear Screen
   matrix.setTextColor(matrix.color555(0,31,0));
   matrix.setCursor(8, 2);
   matrix.println("Countdown");
   matrix.setCursor(8, 14);
   matrix.println("to Start");
  int doOnce5 =1;
  int doOnce4 =1;
  int doOnce3 =1;
  int doOnce2 =1; 
  int doOnce1 =1;
  int doOnce0 =1;
  doOnceTimer = 1;
  doOnceCounter = 1;   
   long time_left = 6500; 
   
   delay(1000);
  while(time_left >=-500 ){
    
  time_left = 6500-millis()+MystartMillis;
  
  if(time_left >5000 && doOnce5 ==1){
    matrix.fillScreen(matrix.color444(0, 0, 0));
    matrix.setTextSize(3); 
    matrix.setTextColor(matrix.color444(0,15,0));
     matrix.setCursor(24,6);
    matrix.print("5");
   doOnce5 =0;
  }
 
    if(time_left <4500 && time_left >4000 && doOnce4 ==1){
      matrix.fillScreen(matrix.color444(0, 0, 0));
      matrix.setCursor(24,6);
      matrix.print("4");
    ledcWriteTone(BuzzerChannel, 1000);
    ledcWrite(BuzzerChannel, 255);
      doOnce4 = 0;
    }
    
  if(time_left <4000 && time_left >3500 ){
      ledcWrite(BuzzerChannel, 0);
  }
      if(time_left <3500 && time_left >3000 && doOnce3 ==1){
        matrix.fillScreen(matrix.color444(0, 0, 0));
        matrix.setCursor(24,6);
         matrix.print("3");
       doOnce3 =0;
    ledcWrite(BuzzerChannel, 255);
     }
     
       if(time_left <3000 && time_left >2500 ){
       ledcWrite(BuzzerChannel, 0);
  }
        if(time_left <2500 && time_left >2000 && doOnce2 ==1){
          matrix.fillScreen(matrix.color444(0, 0, 0));
          matrix.setCursor(24,6);
          matrix.print("2");
          ledcWrite(BuzzerChannel, 255);
          doOnce2 =0;
     }

     if(time_left <2000 && time_left >1500 ){
       ledcWrite(BuzzerChannel, 0);
  }
     if(time_left <1500 && time_left >1000 && doOnce1 ==1){
      matrix.fillScreen(matrix.color444(0, 0, 0));
         matrix.setCursor(24,6);
     matrix.print("1");
     doOnce1 =0;
      ledcWrite(BuzzerChannel, 255);
        }
    
      if(time_left <1000 && time_left >500){
      ledcWrite(BuzzerChannel, 0);
  }
 
   if(time_left <500&& time_left>0 && doOnce0 ==1){
    matrix.fillScreen(matrix.color444(0, 0, 0));
    matrix.setTextSize(2);
        matrix.setCursor(10,8);
    matrix.print("LIFT");
    doOnce0 =0;
   ledcWriteTone(BuzzerChannel, 2000);
  ledcWrite(BuzzerChannel, 200);
    delay(500);
    ledcWrite(BuzzerChannel, 0);
     }
  }
ledcWrite(BuzzerChannel, 0);
  repCounter=0;
  return;
  }
  
// Input a value 0 to 24 to get a color value.
// The colours are a transition r - g - b - back to r.
void  RainbowText(int Y , int X , const char *text){
   matrix.setCursor(Y,X);    // start at line 23, with 3 pixel of spacing
  uint8_t w = 0;
int strLen = strlen(text);
  for (w=0; w<strLen; w++) {
    matrix.setTextColor(Wheel(w));
    matrix.print(text[w]);
  }
  }
  
uint16_t Wheel(byte WheelPos) {
  if(WheelPos < 8) {
   return matrix.color444(15 - WheelPos*2, WheelPos*2, 0);
  } else if(WheelPos < 16) {
   WheelPos -= 8;
   return matrix.color444(0, 15-WheelPos*2, WheelPos*2);
  } else {
   WheelPos -= 16;
   return matrix.color444(0, WheelPos*2, 7 - WheelPos*2);
  }
} // end RainbowText

int CountingREPS(){
 
int repLine = 17;
//For testing purpose
 if(doOnceRepCounter){
  repCounter = 999;
  doOnceRepCounter =0;
  }
  // Button debounce Rep counter UP
   readingRepUP = digitalRead(repButtonUP);
  if (readingRepUP != lastButtonStateRepUP) {
    // reset the debouncing timer
    lastDebounceTime = millis();
  }
  if ((millis() - lastDebounceTime) > debounceDelay) {
     if (readingRepUP != buttonStateRepUP) {
      buttonStateRepUP = readingRepUP;
     if (buttonStateRepUP == HIGH) {
       repCounter++;
     }
   }
}
// Button debounce Rep counter down
 readingRepDOWN = digitalRead(repButtonDOWN);
  if (readingRepDOWN != lastButtonStateRepDOWN) {
    // reset the debouncing timer
    lastDebounceTime = millis();
  }
  if ((millis() - lastDebounceTime) > debounceDelay) {
     if (readingRepDOWN != buttonStateRepDOWN) {
      buttonStateRepDOWN = readingRepDOWN;
     if (buttonStateRepDOWN == HIGH) {
      if(repCounter > 0){
       repCounter--;
      }
     }
   }
}

// prints the reps 
if(repCounter == 0 && doOnceCounter ==1 ){ // So it prints to begin with
   matrix.setTextSize(2); 
   matrix.fillRect(27, repLine, 32,16, matrix.color444(0, 0, 0)); // overwrite the text with black
   matrix.setTextColor(matrix.color444(1,8,15));
   matrix.setCursor(27,repLine);
   matrix.print(repCounter);
   lastRepWas = repCounter;
   doOnceCounter = 0;
   }

if(repCounter != lastRepWas  ){
  
  if(repCounter >= 0 && repCounter <10 && doOnceCounter == 0){
   matrix.setTextSize(2); 
   matrix.fillRect(21, repLine,34,14, matrix.color444(0, 0, 0)); // overwrite the text with black
   matrix.setTextColor(matrix.color444(1,8,15));
   matrix.setCursor(27,repLine);
   matrix.print(repCounter);
   lastRepWas = repCounter;
   }
  if(repCounter >= 10 && repCounter <100){
   matrix.setTextSize(2); 
   matrix.fillRect(15, repLine, 40,14, matrix.color444(0, 0, 0)); // overwrite the text with black
   matrix.setTextColor(matrix.color444(1,8,15));
   matrix.setCursor(21,repLine);
   matrix.print(repCounter);
   lastRepWas = repCounter;
   }

     if(repCounter >= 100 && repCounter <1000){
   matrix.setTextSize(2); 
   matrix.fillRect(9, repLine, 48,14, matrix.color444(0, 0, 0)); // overwrite the text with black
   matrix.setTextColor(matrix.color444(1,8,15));
   matrix.setCursor(15,repLine);
   matrix.print(repCounter);
   lastRepWas = repCounter;
   }

        if(repCounter >= 1000 && repCounter <10000){
   matrix.setTextSize(2); 
   matrix.fillRect(3, repLine, 58,14, matrix.color444(0, 0, 0)); // overwrite the text with black
   matrix.setTextColor(matrix.color444(1,8,15));
   matrix.setCursor(9,repLine);
   matrix.print(repCounter);
   lastRepWas = repCounter;
   }

   if(repCounter >= 10000 && repCounter <100000){
   matrix.setTextSize(2); 
   matrix.fillRect(3, repLine, 58,14, matrix.color444(0, 0, 0)); // overwrite the text with black
   matrix.setTextColor(matrix.color444(1,8,15));
   matrix.setCursor(3,repLine);
   matrix.print(repCounter);
   lastRepWas = repCounter;
   }
   
   }
 // storing old reading values for later use
  lastButtonStateRepUP = readingRepUP;
  lastButtonStateRepDOWN = readingRepDOWN;
 
  return repCounter;
  }


    void horn(){
    ledcWriteTone(BuzzerChannel, 2000);
    ledcWrite(BuzzerChannel, 200);
    delay(2000);
    ledcWrite(BuzzerChannel, 0);
    run_pause=1;
  }

    void shortHorn(){
    ledcWriteTone(BuzzerChannel, 2000);
    ledcWrite(BuzzerChannel, 255);
    delay(750);
    ledcWrite(BuzzerChannel, 0);
    run_pause=1;
  }
  
  void time_fraction(unsigned long brutto){
 matrix.setTextColor(matrix.color444(15,0,0));
 matrix.setTextSize(2);
    if(doOnceTimer){
    mm_10_old = 10;
    mm_1_old = 10;
    ss_10_old = 10;
    ss_1_old = 10;
     matrix.setCursor(27,1);
     matrix.print(":");
     doOnceTimer=0;
      }
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

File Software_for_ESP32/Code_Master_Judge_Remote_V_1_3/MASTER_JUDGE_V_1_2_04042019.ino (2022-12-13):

#include <Adafruit_GFX.h>
#include <Adafruit_ILI9341.h>
#include <SPI.h>
#include <nRF24L01.h>
#include <RF24.h>

#define CE_PIN  27
#define CSN_PIN 26  
#define CLK_SPI 18 // 18
#define MISO 19 // 19
#define MOSI 23 //23
#define SS 15 // HSPI 15 // Yes same pin as CSN, but it doesn't seem to matter.

// Corrected 29012019 for my use on ESP32. HSPI //EHB
#define _cs  17  // goes to TFT CS (17)
#define _dc  16  // goes to TFT DC (16)
#define _mosi 23  // goes to TFT MOSI (23)
#define _sclk 18  // goes to TFT SCK/CLK (18)
#define _rst  5   // goes to TFT RESET (5)
#define _miso 19   // Not connected
//       3.3V     // Goes to TFT LED  
//       5v       // Goes to TFT Vcc
//       Gnd      // Goes to TFT Gnd     

Adafruit_ILI9341 tft = Adafruit_ILI9341(_cs, _dc, _rst);

// Butten and buzzer pins
#define repButtonUP 34
#define buttonPin 35    // select/menu
#define repButtonDOWN 32
#define channelSwitch 33

// Variables for general functions.
int8_t countState = LOW;         // the current state of the output pin
int8_t buttonState;             // the current reading from the input pin
int8_t lastButtonState = LOW;   // the previous reading from the input pin
int8_t buttonStateRepUP;             // the current reading from the input pin
int8_t lastButtonStateRepUP = LOW; 
int8_t buttonStateRepDOWN;             // the current reading from the input pin
int8_t lastButtonStateRepDOWN = LOW; 
int8_t readingRepUP;
int8_t readingRepDOWN;
int8_t reading;
int8_t lastButtonStateRepDOWNRESET; 
int8_t buttonStateRepDOWNRESET;
int8_t readingRepDOWNRESET;
uint8_t TRANSMITMenu =0;
uint8_t InitializationMENU = 0;
uint8_t Menu =1; 
uint8_t choiceMade =0;
uint8_t Select =0;
uint8_t CountUP = 0;
uint8_t CountDOWN = 0;
uint8_t Pentathlon = 0;
uint8_t doOnceCount = 1;
uint8_t setCountdownTimer =1 ;
uint8_t doOnceTRANSMITMENU =1;
uint8_t SetTimerMenu =0;
uint8_t runningDiscipline = 0;
uint8_t doOncerunningDiscipline =1;
uint8_t countDowntoStart = 1;
int8_t CDT_hh_1 = 0;
int8_t CDT_mm_10 = 0;
int8_t CDT_mm_1 = 0;
int8_t CDT_ss_10 = 0;
int8_t CDT_ss_1 = 0;
int8_t CDT_menu = 1;
int8_t CDT_menu_Last =0;
int8_t CDT_var_val =0;
int8_t hh_1_old = 10;
int8_t mm_10_old = 10;
int8_t mm_1_old = 10;
int8_t ss_10_old = 10;
int8_t ss_1_old = 10;
int i ;
int j;
int lineSetCDT = 140; // line definition for bars
int radioTXitterations = 10;
uint8_t fourDigits = 0;
uint8_t doOnceTimer = 1;
unsigned long oldMasterMillis = 0;
unsigned long lastDebounceTime = 0;  // the last time the output pin was toggled
unsigned long debounceDelay = 20;    // the debounce time; increase if the output flickers
unsigned long timeHolder2;
unsigned long timeHolder1;
long startMillis;
long currentMillis;
long difference_millis;
unsigned long oldTimerForTX = 0;
unsigned long mm_10 = 0;
unsigned long mm_1 = 0;
unsigned long hh_10 = 0; 
unsigned long hh_1 = 0;
unsigned long ss_10 = 0;
unsigned long ss_1 = 0;
long hours_10 = 36000000;
long hours_1 = 3600000;
long minutes_10 = 600000;
long minutes_1 = 60000;
long seconds_10 = 10000;
long seconds_1 = 1000;

//////////////////////////////////////////////////////////
//
//  RADIO SPECIFIC VARIABLES ETC
//
//////////////////////////////////////////////////////////

bool doOnceRadio = true;
RF24 radio(CE_PIN,CSN_PIN);

const uint64_t pipe1 = 0xE8E8EEF0A1LL;
const uint64_t pipe2 = 0xE8E8EEF0A2LL;  
const uint64_t pipe3 = 0xE8E8EEF0A3LL;
const uint64_t pipe4 = 0xE8E8EEF0A4LL;
const uint64_t pipe5 = 0xE8E8EEF0A5LL;
const uint64_t pipe6 = 0xE8E8EEF0A6LL;
  


typedef struct {
  char filterChar[1];
  bool startBit;
  bool reset1;
  uint8_t setDiscipline;
  unsigned long setDuration;
  unsigned long masterMillis;
  bool returnResult;
  uint16_t result;
  bool switchChannel;
  bool reset2;
  } TXstruct;

  TXstruct message;


////////////////////////////////////////////////
//
//  SETUP
//
////////////////////////////////////////////////

void setup() {
 
  //Serial.begin(115200);

   pinMode(repButtonUP, INPUT); // Counter increment
  pinMode(repButtonDOWN, INPUT); // Counter decrement
  pinMode(buttonPin, INPUT); // Start/Stop
  pinMode(channelSwitch, INPUT );

 
  tft.begin();
  tft.setRotation(3);
  tft.fillScreen(ILI9341_BLACK);
  tft.setTextSize(3);
  tft.println("Starting...");
  delay(1000);
  MainText();
  delay(1000);
 PrintMainMenu();
} 

///////////////////////////////////
//
// main LOOP
//
/////////////////////////////////

void loop() {


buttonPressedLoopTOP(); // TOP section for buttons

  if(Menu>4 ){  Menu = 1;  } // KEEPS MENU WITHIN BOUNDS
  if(Menu<1){  Menu = 4;  }


 
if(Menu==1 && !choiceMade){
  tft.setTextSize(4);
  tft.fillRect(10, 125, 20 ,30, ILI9341_WHITE) ; // overwrite the text with white
  tft.fillRect(10, 165, 20 ,30, ILI9341_WHITE) ; // overwrite the text with white
  tft.fillRect(10, 205, 20 ,30, ILI9341_WHITE) ; // overwrite the text with white
  tft.setTextColor(ILI9341_RED);
  tft.setCursor(10, 85); 
  tft.println("*");
 if(Select){
    message.setDiscipline = 1;
    CountDOWN = 1;
    choiceMade = 1;
    SetTimerMenu =1;
   }
   }

   if(Menu==2 && !choiceMade){
    tft.setTextSize(4);
  tft.fillRect(10, 85, 20 ,30, ILI9341_WHITE) ; // overwrite the text with white
  tft.fillRect(10, 165, 20 ,30, ILI9341_WHITE) ; // overwrite the text with white
  tft.fillRect(10, 205, 20 ,30, ILI9341_WHITE) ; // overwrite the text with white
  tft.setTextColor(ILI9341_RED);
  tft.setCursor(10, 125); 
  tft.println("*");
  if(Select){
    message.setDiscipline = 2;
    CountUP = 1;
    choiceMade = 1;
    SetTimerMenu =1;
    }
   }


   if(Menu==3 && !choiceMade){
    tft.setTextSize(4);
  tft.fillRect(10, 85, 20 ,30, ILI9341_WHITE) ; // overwrite the text with white
  tft.fillRect(10, 125, 20 ,30, ILI9341_WHITE) ; // overwrite the text with white
  tft.fillRect(10, 205, 20 ,30, ILI9341_WHITE) ; // overwrite the text with white
  tft.setTextColor(ILI9341_RED);
  tft.setCursor(10, 165); 
  tft.println("*");
  if(Select){
    Pentathlon = 1;
    choiceMade = 1;
    InitializationMENU = 1;
    timeHolder1 = 3000000; // set time to 50 min
    message.setDiscipline = 3;   // set discipline to pentathlon
    }
   }

      if(Menu==4 && !choiceMade){
    tft.setTextSize(4);
  tft.fillRect(10, 85, 20 ,30, ILI9341_WHITE) ; // overwrite the text with white
  tft.fillRect(10, 125, 20 ,30, ILI9341_WHITE) ; // overwrite the text with white
  tft.fillRect(10, 165, 20 ,30, ILI9341_WHITE) ; // overwrite the text with white
  tft.setTextColor(ILI9341_RED);
  tft.setCursor(10, 205); 
  tft.println("*");
  if(Select){
    choiceMade = 1;
  resettingFunction();
    }
   }

//////////////////////////////////////
//
// Set timer menu
//
/////////////////////////////////////
while(SetTimerMenu){
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

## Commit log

2022-12-13 First upload. Fingers crossed that it works.
    [Kettlebell_counter_BOM.xlsx]
2022-12-13 Drawings of the alu frames
2023-01-11 Updated BOM, and CAD pictures
    [Kettlebell_counter_BOM.xlsx]
2023-01-18 STL files added
    The process of making of 3D printed frame has been completed, and the STL files are now available in "Frame_and_mounting_instructions" which include a tool and component list.
    Remember to read "Readme_3D_print.txt
    [End_frame_L.stl, End_frame_R.stl, Mid_frame.stl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]
2023-02-17 Added description of how to install the IDE, Libraries and boards. Massive folder clean up. Now everything is in one of three main folders: PCB , Mechanics or Software_for_ESP32
    [End_frame_L.stl, End_frame_R.stl, Kettlebell_counter_BOM.xlsx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]
2023-02-23 Judge box remote files uploaded into the mechanics folder
    The .svg and .lbrn flies for the judge box remote have been added to the mechanics/SVG_files folder.
    The files are designed for 3mm plywood. Note that there are help lines which should not be printet.
